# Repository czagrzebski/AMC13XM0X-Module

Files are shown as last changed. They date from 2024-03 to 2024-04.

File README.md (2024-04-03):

# AMC13XM0X-Module for Industrial Sensors

A PCB design for the [TI AMC13XM0X](https://www.ti.com/product/AMC131M02) $\Delta\Sigma$ ADC module. The module is designed to interface with industrial sensors that support 0-10V or 4-20mA output. This module features a voltage and current sensing network connected to the differential inputs of the ADC. The module is designed to be used over Serial Peripheral Interface (SPI) communication protocol. 

The module features a 4-layer PCB design with a 2.54mm pitch header for interfacing with the host controller. The module is powered by a 3V3 supply. The module is designed to be used in industrial applications where high accuracy and reliability are required. The module is designed to be used with the TI AMC13XM0X $\Delta\Sigma$ ADC.

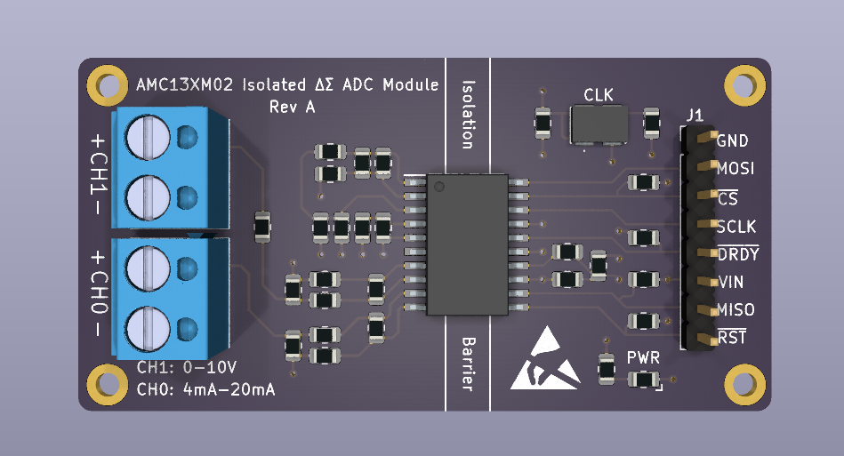
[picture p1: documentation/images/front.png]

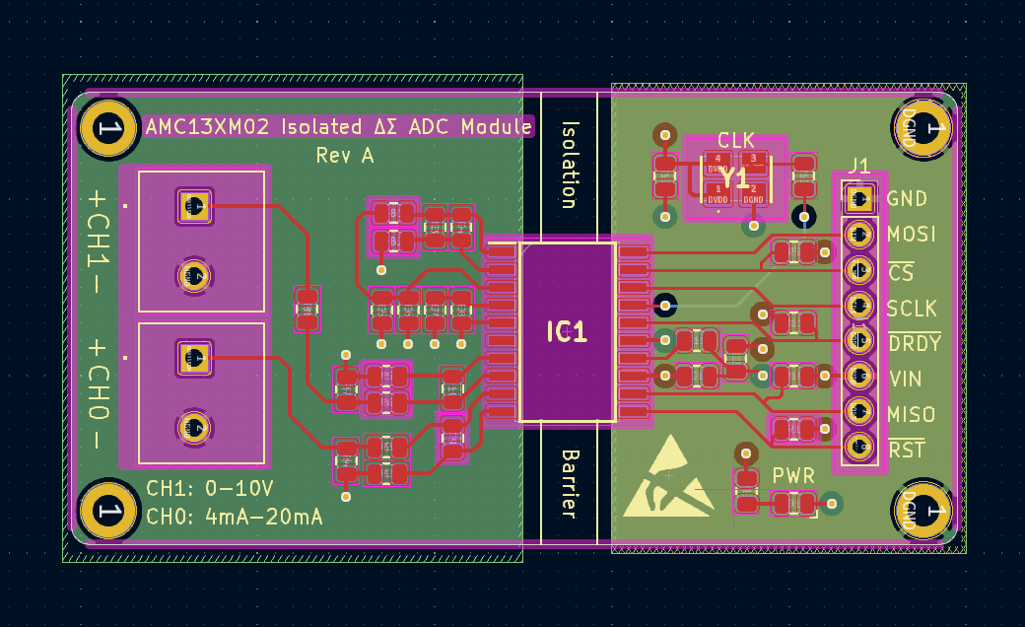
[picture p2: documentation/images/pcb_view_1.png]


# AMC13XM0X ADC Overview

The AMC13XMOX $\Delta\Sigma$ ADC is a high-precision, power isolated, simultaneous-sampling, 24-bit ADC. The AMC13XM02 features a fully integrated isolated DC/DC converter that allows single-supply operation from the low-side of the device. The reinforced and capactive isolation barrier is certified according to VDE V 0884-17 and UL1577. The isolation barrier is made of a $SiO_2$ barrier that provides $7070-V_{PEAK}$ reinforced isolation, per DIN EN IEC 60747-17.

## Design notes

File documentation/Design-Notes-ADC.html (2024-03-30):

# PCB for AMC131M02 Reinforced Isolated Delta-Sigma ADC with SPI Interface¶

### Creed Zagrzebski¶

The AMC131M02 is a precision, two-channel, delta-sigma (ΔΣ) modulator with the output separated from the input circuitry by capacitive isolation. The input of the AMC131M02 is optimized to interface directly with shunt resistors for current monitoring or with a voltage divider for measuring voltage. The AMC131M02 features a fully integrated isolated DC/DC converter that allows a single-supply operation from the low-side of the device. The AMC131M02 is certified according to VDE V 0884-17 and UL1577 and is suitable for use in industrial applications requiring high precision and reinforced isolation. The isolation barrier separates parts of the system that operate on different common-mode voltage levels and protects lower voltage systems from damage, making the AMC131M02 an ideal solution for systems that need to measure small differential voltages in the presence of large common-mode voltages.

This reference design is a complete solution for safely measuring industrial sensor signals. One channel is dedicated towards measuring a 0-10V voltage signal, and the other channel is dedicated towards measuring a 4-20mA current signal. The design is powered by a single 3.3V supply, and the output data is sent to a microcontroller via SPI. The design is reinforced isolated, and the isolation voltage is rated at 5kV RMS.

This document goes over the calculations and design considerations for the AMC131M02 development board and provides a complete bill of materials (BOM) for the design.

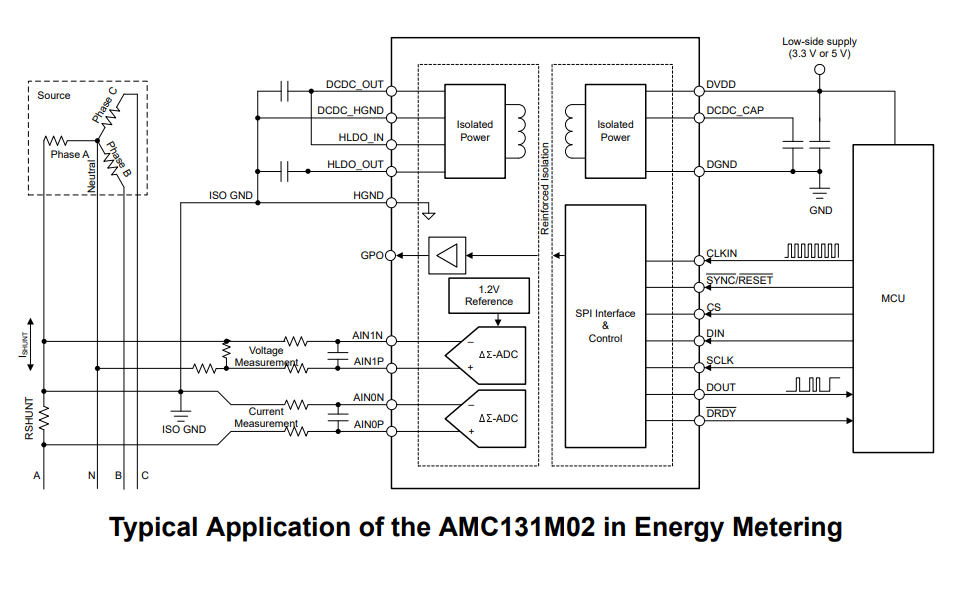
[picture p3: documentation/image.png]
No description has been provided for this image


## PCB Schematic¶

The schematic for the AMC131M02 development board is shown below. The design is powered by a single 3.3V supply, and the output data is sent to a microcontroller via SPI. The design is reinforced isolated, and the isolation voltage is rated at 5kV RMS.

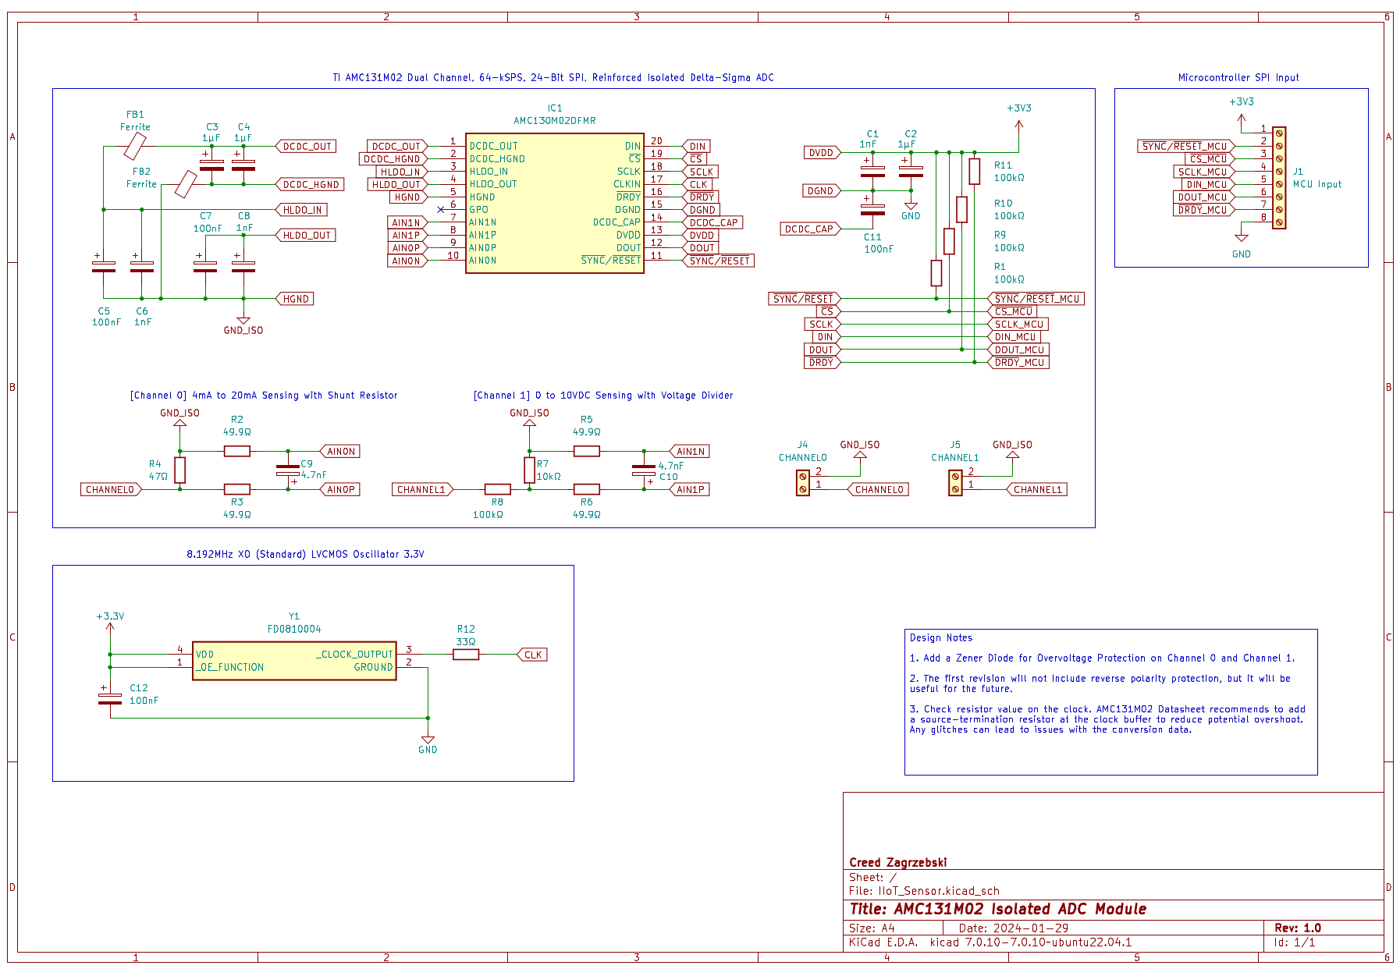
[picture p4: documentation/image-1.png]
No description has been provided for this image


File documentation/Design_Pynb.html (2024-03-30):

## Design Document for a Analog Isolation Module using the IL300 Linear Optocoupler with Non-Inverting/Unipolar Photoconductive Configuration¶

### Author: Creed Zagrzebski¶

### Date: 2/8/2024¶

#### Overview¶

This document goes over the design of a analog isolation module using the IL300 optocoupler. The IL300 is a linear optocoupler that is used to transfer an analog signal from one circuit to another while providing electrical isolation. The IL300 is a bipolar device and is used in a variety of applications such as analog signal isolation, voltage level shifting, and linear amplification. The IL300 is a versatile device that can be used in a variety of applications and is a good choice for linear amplification due to its high linearity and low distortion.

For this project, the IL300 will be used to convert analog signals from the 12V industrial sensor (thermocouples, strain gauges, pressure transducers, time of flight) to the 3.3V ADC input on the ESP32 Microcontroller. The IL300 will be used in a non-inverting configuration to amplify the signal from the sensor and provide electrical isolation between the sensor and the microcontroller. The design will follow the Unipolar Photovoltaic Amplifier Mode of Operation.

Photoconductive mode of operation is better than photovoltaic mode of operation for the following reasons:

- The photoconductive mode of operation has a faster response time than the photovoltaic mode of operation. This is because the photoconductive mode of operation has a lower output impedance than the photovoltaic mode of operation. This allows the photoconductive mode of operation to respond faster to changes in the input signal.
- The photoconductive mode of operation has a higher bandwidth than the photovoltaic mode of operation. This is because the photoconductive mode of operation has a lower output impedance than the photovoltaic mode of operation. This allows the photoconductive mode of operation to have a higher bandwidth than the photovoltaic mode of operation.

The IL300 consists of a high efficiency AIGaAs LED emitter coupled to two independent PIN photodiodes. The servo photodiode is used to provide feedback to the LED driver to maintain a constant output which controls the current to the LED emitter. This photodiode provides a photocurrent, $I_\text{P1}$, that is directly proportional to the LED's incident flux. This servo operation linearizes the LED's output flux and eliminates the LED's time and temperature dependency. The galvanic isolation between the input and the output is provided by a second PIN photodiode located on the output side of the coupler. The output current, $I_\text{P2}$ from this diode accurately tracks the photocurrent generated by the servo photodiode.

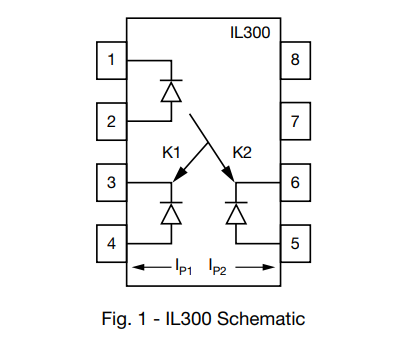
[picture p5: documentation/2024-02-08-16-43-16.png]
Pin


#### Electrical Characteristics¶

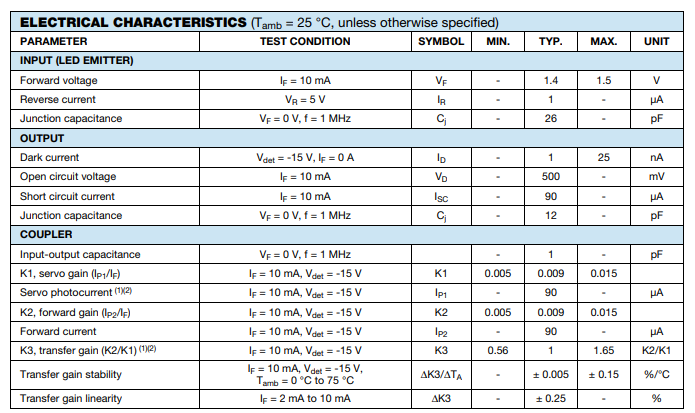
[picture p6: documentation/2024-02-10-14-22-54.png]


#### Circuit Implementation and Analysis¶

Below is a picture containing the circuit diagram of the Unipolar Photoconductive Isolation Amplifier Mode of Operation from the Optocoupler Application Note 50 (https://www.vishay.com/docs/83708/appnote50.pdf).

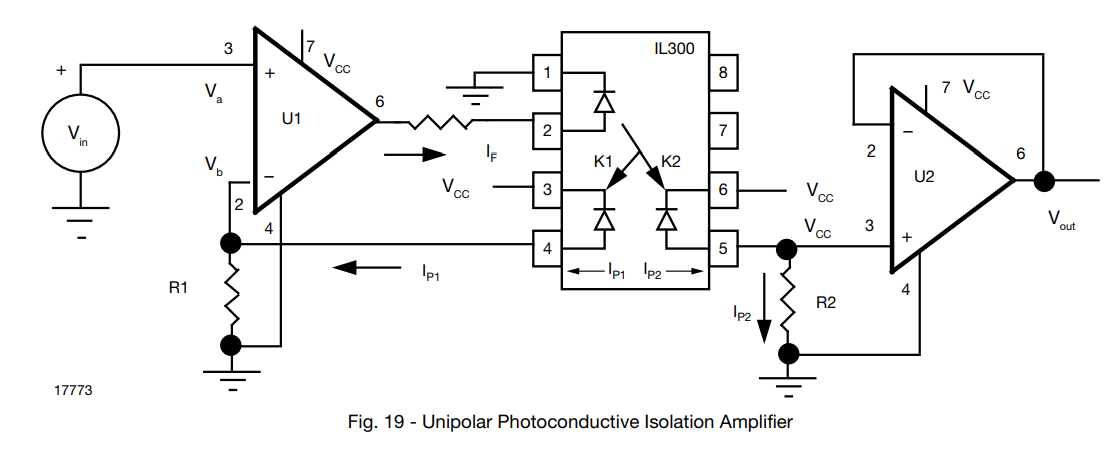
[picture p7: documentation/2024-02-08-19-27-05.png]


A few notes about the circuit:

- The $V_\text{CC}$ signal on both sides of the IL300 should not be the same power supply. This is because the IL300 is designed to provide electrical isolation between the input and output. If the same power supply is used, the isolation will be compromised. Also, the $V_\text{CC}$ signal on the output side of the IL300 should be at 3.3V to match the input of the ESP32 microcontroller.
- Values for R1 and R2 need to be calculated to ensure the proper gain is achieved.

##### Calculating R1 and R2¶

The gain of this amplifier is given by the following equation:

$$\dfrac{V_\text{out}}{V_\text{in}} = G = K3 * (\dfrac{R2}{R1})$$

$R1$ sets the input signal range in conjunction with the servo gain and the maximum output current, $I_O$ which U1 can source. Given this, $I_{O_{\text{max}}} = I_{F_{\text{max}}}$

Now, let's assume that the gain value is 1.0, meaning that there is no amplification of the input signal. In fact, we are deamplifying the signal. This is a good starting point to ensure that the circuit is working properly. However, a gain of 1.0 will work just fine for our purposes. Next, the data sheet states that the typical value of K3 is 1.0. This means that the value of K3 is 1.0. Using this ratio we know that $\dfrac{R2}{R1} = 1.0$, thus $R2 = R1$. Finally, we need to calculate the value of $R1$ and thus we also get the value of $R2$ from the following equation:

$$R1 = \dfrac{V_\text{in}}{K1 * I_{F_{\text{max}}}}$$

According to the typical operating conditions of the IL300, the value of $K1$ is 0.012 and the value of $I_{F_{\text{max}}}$ is 12mA, $V_D$ = 15V, and $T_{ambient}$ is 25 degrees Celsius.

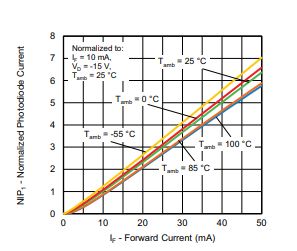
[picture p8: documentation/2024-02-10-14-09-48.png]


Thus, we can calculate the value of $R1$ as follows:

$$R1 = \dfrac{12V}{0.012 * 0.012A} = 83333\Omega \approx 100k \Omega = R2$$

Thus our values for $R1$ and $R2$ are 100k $\Omega$.

##### Biasing the non-inverting input¶

Because we are not using a rail-to-rail op-amp, we need to bias the non-inverting input to the middle of the supply voltage in order to get the full range of our analog signal. This is done by using a voltage divider. The voltage divider is made up of two resistors, $R3$ and $R4$. The voltage at the non-inverting input is given by the following equation:

$$V_{\text{inverting}} = V_{\text{CC}} * \dfrac{R4}{R3 + R4}$$

For a 12V signal, we are going to use a $10k\Omega$ resistor for $R3$ and a $1.8k\Omega$ resistor for $R4$. This will give us a voltage of 1.8V at the non-inverting input.

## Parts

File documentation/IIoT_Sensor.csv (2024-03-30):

Source: | /home/czagrzebski/Projects/IIoT_Sensor_ADC/IIoT_Sensor.kicad_sch
Date: | Mon 25 Mar 2024 08:36:47 PM CDT
Tool: | Eeschema 7.0.10-7.0.10~ubuntu22.04.1
Generator: | /usr/share/kicad/plugins/bom_csv_grouped_by_value.py
Component Count: | 33
Collated Components:
Item | Qty | Reference(s) | Value | LibPart | Footprint | Datasheet | DNP | Height | Manufacturer_Name | Manufacturer_Part_Number | Mouser Part Number | Mouser Price/Stock
1 | 4 | C1, C4, C6, C8 | 1nF | Device:C_Polarized | Resistor_SMD:R_0805_2012Metric | https://www.digikey.com/en/products/detail/kemet/C0805C102K5RAC7800/411146
2 | 2 | C2, C3 | 1µF | Device:C_Polarized | Resistor_SMD:R_0805_2012Metric | https://www.digikey.com/en/products/detail/samsung-electro-mechanics/CL21B105KBFNNNE/3886687
3 | 4 | C5, C7, C11, C12 | 100nF | Device:C_Polarized | Resistor_SMD:R_0805_2012Metric | https://www.digikey.com/en/products/detail/yageo/CC0805KRX7R9BB104/302874
4 | 2 | C9, C10 | 4.7nF | Device:C_Polarized | Resistor_SMD:R_0805_2012Metric | https://www.digikey.com/en/products/detail/murata-electronics/GRM2165C1H472JA01D/666693
5 | 1 | D1 | LED | Device:LED | Resistor_SMD:R_0805_2012Metric | https://www.digikey.com/en/products/detail/w%C3%BCrth-elektronik/150080SS75000/4489921
6 | 2 | FB1, FB2 | Ferrite | Device:FerriteBead | Resistor_SMD:R_0805_2012Metric | https://www.digikey.com/en/products/detail/w%C3%BCrth-elektronik/742792090/1639012
7 | 1 | IC1 | AMC130M02DFMR | Lib_AMC130:AMC130M02DFMR | Custom:AMC130M02DFMR | https://www.ti.com/lit/ds/symlink/amc130m02.pdf?ts=1703733915918 |  | 3.55 | Texas Instruments | AMC130M02DFMR | 595-AMC130M02DFMR | https://www.mouser.co.uk/ProductDetail/Texas-Instruments/AMC130M02DFMR?qs=HoCaDK9Nz5eSLJJXUYivvA%3D%3D
8 | 1 | J1 | MCU Input | Connector:Screw_Terminal_01x08 | Connector_PinHeader_2.54mm:PinHeader_1x08_P2.54mm_Vertical | https://www.digikey.com/en/products/detail/w%C3%BCrth-elektronik/61300811121/4846839
9 | 1 | J4 | CHANNEL0 | Connector:Screw_Terminal_01x02 | Custom:CUI_TB001-500-02BE | https://www.digikey.com/en/products/detail/cui-devices/TB001-500-02BE/10064058
10 | 1 | J5 | CHANNEL1 | Connector:Screw_Terminal_01x02 | Custom:CUI_TB001-500-02BE | https://www.digikey.com/en/products/detail/cui-devices/TB001-500-02BE/10064058
11 | 4 | R1, R9, R10, R11 | 100kΩ | Device:R | Resistor_SMD:R_0805_2012Metric | https://www.digikey.com/en/products/detail/yageo/RC0805FR-07100KL/727544
12 | 4 | R2, R3, R5, R6 | 49.9Ω | Device:R | Resistor_SMD:R_0805_2012Metric | https://www.digikey.com/en/products/detail/panasonic-electronic-components/ERJ-6ENF49R9V/111027
13 | 1 | R4 | 27Ω | Device:R | Resistor_SMD:R_0805_2012Metric | https://www.digikey.com/en/products/detail/yageo/RC0805FR-0727RL/727779
14 | 1 | R7 | 619Ω | Device:R | Resistor_SMD:R_0805_2012Metric | https://www.digikey.com/en/products/detail/yageo/RC0805FR-07619RL/728079
15 | 1 | R8 | 10kΩ | Device:R | Resistor_SMD:R_0805_2012Metric | https://www.digikey.com/en/products/detail/panasonic-electronic-components/ERA-6AEB103V/1465773
16 | 1 | R12 | 33Ω | Device:R | Resistor_SMD:R_0805_2012Metric | https://www.digikey.com/en/products/detail/vishay-dale/CRCW080533R0FKEA/1175466
17 | 1 | R13 | 68Ω | Device:R | Resistor_SMD:R_0805_2012Metric | https://www.digikey.com/en/products/detail/vishay-dale/CRCW080568R0FKEAC/7922338
18 | 1 | Y1 | FD0810004 | LIB_FD0810004:FD0810004 | Custom:FD0810004 | https://www.digikey.com/en/products/detail/diodes-incorporated/FD0810004/2684041 |  | 1.3 | Diodes Incorporated | FD0810004 | 621-FD0810004 | https://www.mouser.co.uk/ProductDetail/Diodes-Incorporated/FD0810004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

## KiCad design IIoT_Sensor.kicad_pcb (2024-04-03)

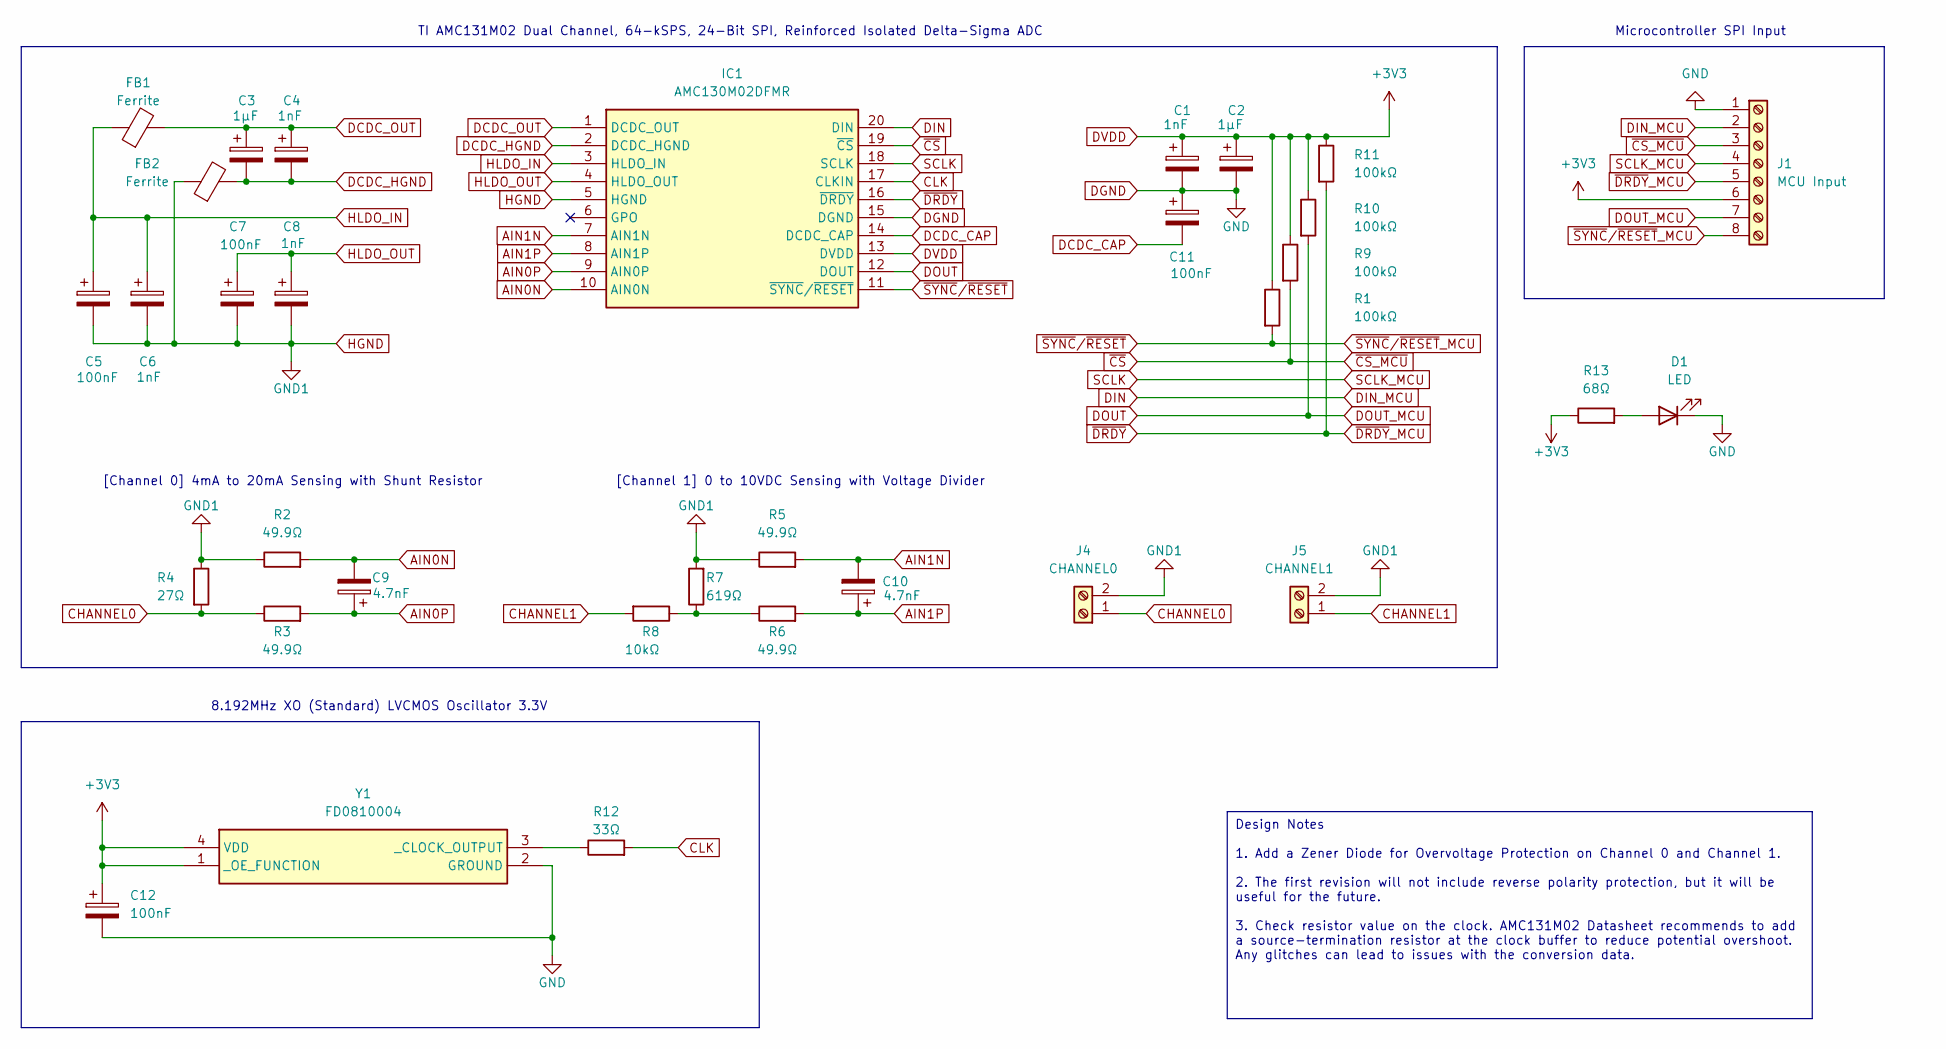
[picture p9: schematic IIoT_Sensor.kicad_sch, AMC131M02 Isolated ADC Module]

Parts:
C1, C4, C6, C8: 1nF; R_0805_2012Metric; DigiKey_Part_Number 399-C0805C102K5RAC7800CT-ND
C2, C3: 1µF; R_0805_2012Metric; DigiKey_Part_Number 1276-1029-1-ND
C5, C7, C11, C12: 100nF; R_0805_2012Metric; DigiKey_Part_Number 311-1140-1-ND
C9, C10: 4.7nF; R_0805_2012Metric; DigiKey_Part_Number 490-3044-1-ND
D1: LED; R_0805_2012Metric; DigiKey_Part_Number 732-4985-1-ND
FB1, FB2: Ferrite; R_0805_2012Metric; DigiKey_Part_Number 732-1608-1-ND
IC1: AMC130M02DFMR; Mouser Part Number 595-AMC130M02DFMR
J1: MCU Input; PinHeader_1x08_P2.54mm_Vertical; DigiKey_Part_Number 732-5321-ND
J4: CHANNEL0; CUI_TB001-500-02BE; DigiKey_Part_Number 102-6134-ND
J5: CHANNEL1; CUI_TB001-500-02BE; DigiKey_Part_Number 102-6134-ND
R1, R9, R10, R11: 100kΩ; R_0805_2012Metric; DigiKey_Part_Number 311-100KCRCT-ND
R2, R3, R5, R6: 49.9Ω; R_0805_2012Metric; DigiKey_Part_Number P49.9CCT-ND
R4: 27Ω; R_0805_2012Metric; DigiKey_Part_Number 311-27.0CRCT-ND
R7: 619Ω; R_0805_2012Metric; DigiKey_Part_Number 311-619CRCT-ND
R8: 10kΩ; R_0805_2012Metric; DigiKey_Part_Number P10KDACT-ND
R12: 33Ω; R_0805_2012Metric; DigiKey_Part_Number 541-33.0CCT-ND
R13: 68Ω; R_0805_2012Metric; DigiKey_Part_Number 541-CRCW080568R0FKEACCT-ND
Y1: FD0810004; Mouser Part Number 621-FD0810004

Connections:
AIN0N: C9.2, IC1.10 (AIN0N), R2.2
AIN0P: C9.1, IC1.9 (AIN0P), R3.2
AIN1N: C10.2, IC1.7 (AIN1N), R5.2
AIN1P: C10.1, IC1.8 (AIN1P), R6.2
CHANNEL0: J4.1, R3.1, R4.2
CHANNEL1: J5.1, R8.2
CLK: IC1.17 (CLKIN), R12.2
DCDC_CAP: C11.2, IC1.14 (DCDC_CAP)
DCDC_HGND: C3.2, C4.2, FB2.2, IC1.2 (DCDC_HGND)
DCDC_OUT: C3.1, C4.1, FB1.2, IC1.1 (DCDC_OUT)
DGND: C1.2, C2.2, C11.1, C12.2, D1.1 (K), IC1.15 (DGND), J1.1, Y1.2 (GROUND)
DIN: IC1.20 (DIN), J1.2
DOUT: IC1.12 (DOUT), J1.7, R10.2
DVDD: C1.1, C2.1, C12.1, IC1.13 (DVDD), J1.6, R1.1, R9.1, R10.1, R11.1, R13.1, Y1.1 (_OE_FUNCTION), Y1.4 (VDD)
HGND: C5.2, C6.2, C7.2, C8.2, FB2.1, IC1.5 (HGND), J4.2, J5.2, R2.1, R4.1, R5.1, R7.2
HLDO_IN: C5.1, C6.1, FB1.1, IC1.3 (HLDO_IN)
HLDO_OUT: C7.1, C8.1, IC1.4 (HLDO_OUT)
unnamed: D1.2 (A), R13.2
unnamed: R6.1, R7.1, R8.1
unnamed: R12.1, Y1.3 (_CLOCK_OUTPUT)
SCLK: IC1.18 (SCLK), J1.4
~CS_MCU: IC1.19 (~CS), J1.3, R9.2
~DRDY: IC1.16 (~DRDY), J1.5, R11.2
~SYNC/~RESET: IC1.11 (~SYNC/~RESET), J1.8, R1.2

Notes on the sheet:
Design Notes 1. Add a Zener Diode for Overvoltage Protection on Channel 0 and Channel 1. 2. The first revision will not include reverse polarity protection, but it will be useful for the future. 3. Check resistor value on the clock. AMC131M02 Datasheet recommends to add a source-termination resisto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
8.192MHz XO (Standard) LVCMOS Oscillator 3.3V
[Channel 0] 4mA to 20mA Sensing with Shunt Resistor
[Channel 1] 0 to 10VDC Sensing with Voltage Divider
TI AMC131M02 Dual Channel, 64-kSPS, 24-Bit SPI, Reinforced Isolated Delta-Sigma ADC
Microcontroller SPI Input

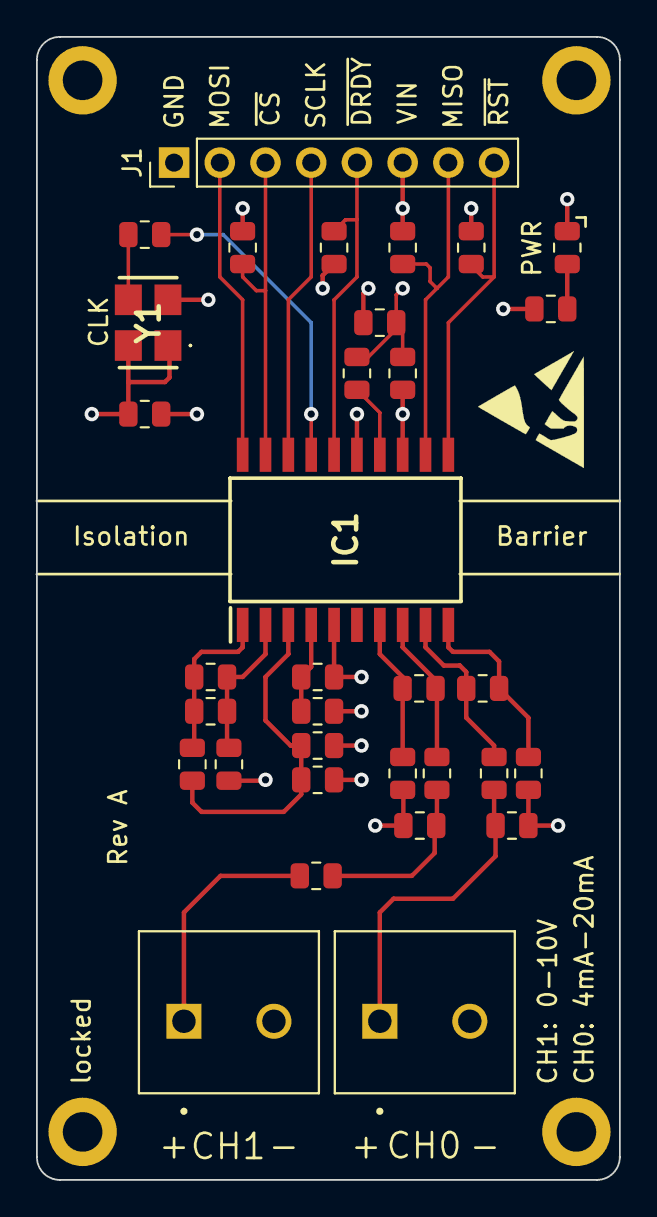
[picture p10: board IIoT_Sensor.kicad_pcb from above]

Board: 4 copper layers, 32.4 x 63.5 mm, 33 parts (0 on the bottom side), 24 nets.

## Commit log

2024-04-03 file organization
    [IIoT_Sensor.csv]
2024-04-03 added pics
    [IIoT_Sensor.csv, IIoT_Sensor.kicad_pcb]
